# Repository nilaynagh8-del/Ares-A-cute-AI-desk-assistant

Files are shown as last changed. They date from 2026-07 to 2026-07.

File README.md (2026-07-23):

# Ares

A desk robot companion with two big, glowing ocean-blue eyes on a round screen.
Ares listens through its onboard microphone, thinks on your PC with **Gemini Live**,
and speaks back through your computer speakers — while its eyes animate idle,
listening, and speaking states.

---

## Quick Start

1. **Flash the firmware** — see [Docs/flashing.md](Docs/flashing.md).
2. **Install the desktop app** — see [Desktop/README.md](Desktop/README.md).
3. Put the robot on WiFi (USB provisioning in the app), connect by IP, paste your
   Gemini API key, and click **Start talking**.

You can also open `http://<robot-ip>/` on your phone — the ESP32 serves a web UI
that uses the robot mic and drives the eyes.

---

## Features

- **Animated robot eyes** — blink, gaze, breathe; states for idle / listening / speaking
- **Onboard PDM mic** streamed over WiFi to the desktop app (or phone web UI)
- **Gemini Live voice assistant** on your PC with web search and safe PC control tools
- **Hands-free wake word** — say "Ares" (local Vosk, no signup)
- **Swipe-down menu** on the round display — brightness slider + robot IP
- **Personality files** — edit `system.md` and `memory.md`; synced to the robot over WiFi
- **System-tray agent** — optional background auto-connect + hands-free mode
- **Camera-ready hardware path** — the ESP32-S3 Sense camera is not integrated in
  this build because the stock ribbon cable is too short for the enclosure layout

---

## Architecture

```
ESP32 mic --(WiFi TCP :8080)-->  Desktop app  -->  Gemini Live
ESP32 eyes <--(state JSON)-------               |
                                                +--> PC speakers
Phone browser --(WebSocket :81)--> robot-served page + Gemini
```

See [Docs/architecture.md](Docs/architecture.md) for ports, pins, and design notes.

---

## What is this?

Ares is a small desk character you can talk to. The ESP32-S3 + round display handles
the face, touch, and microphone. Your PC runs the voice AI (Gemini), plays audio, and
can open apps, search the web, and remember shortcuts on your behalf. Press [here](https://drive.google.com/file/d/1ACdh4I4yCxnCxKJ7vzaC96i0bJgCajry/view?usp=sharing) for a demo.

---

## Hardware

| Part | Role |
|---|---|
| Seeed XIAO ESP32-S3 **Sense** | MCU + onboard PDM microphone |
| Seeed Round Display for XIAO | GC9A01 240x240 round IPS + touch |
| MakerHawk 1000mAh 1S LiPo | Battery power |
| Custom 3D-printed enclosure | Printable files in [CAD/](CAD/) |

Full enclosure files and build notes: [CAD/](CAD/).

### Camera note

The Seeed XIAO ESP32-S3 Sense includes a camera connector/camera module, but Ares
does not currently use it. The stock camera ribbon cable is too short for this
enclosure, so the camera is not routed through the top cutout.

A future build could swap in a compatible camera module or longer ribbon cable,
route it through the top cutout, and extend the firmware/desktop bridge to send
camera frames into Gemini Live for visual analysis with `gemini-3.1-flash-live-preview`.
That would require code changes; the current release is voice-first.

---

## Repo layout

| Folder | Contents |
|---|---|
| [Firmware/](Firmware/) | Arduino sketch for the ESP32 (`RobotEyes.ino`) |
| [Desktop/](Desktop/) | Python companion app (Gemini Live, wake word, tray agent) |
| [Docs/](Docs/) | Flashing, architecture, setup |
| [CAD/](CAD/) | STEP assembly and printable enclosure STLs |

---

## Photos

| Ares on the desk | Low-light glow |
|---|---|
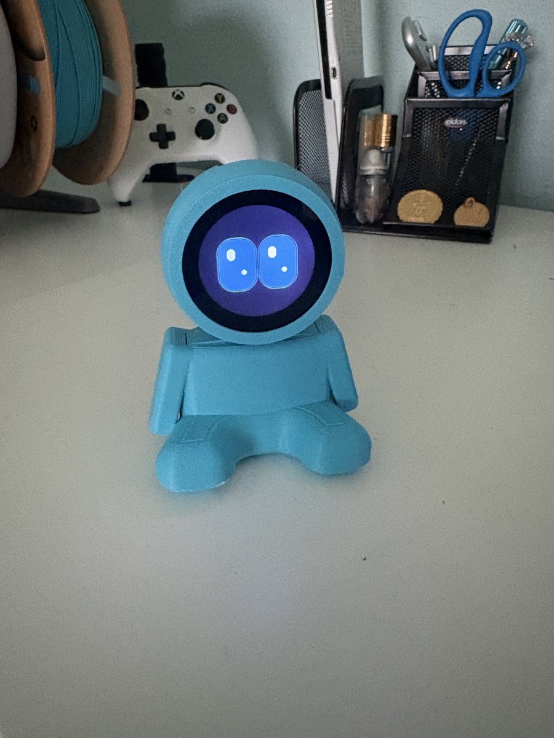
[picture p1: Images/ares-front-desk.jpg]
Ares on a desk with blue printed body and animated eyes
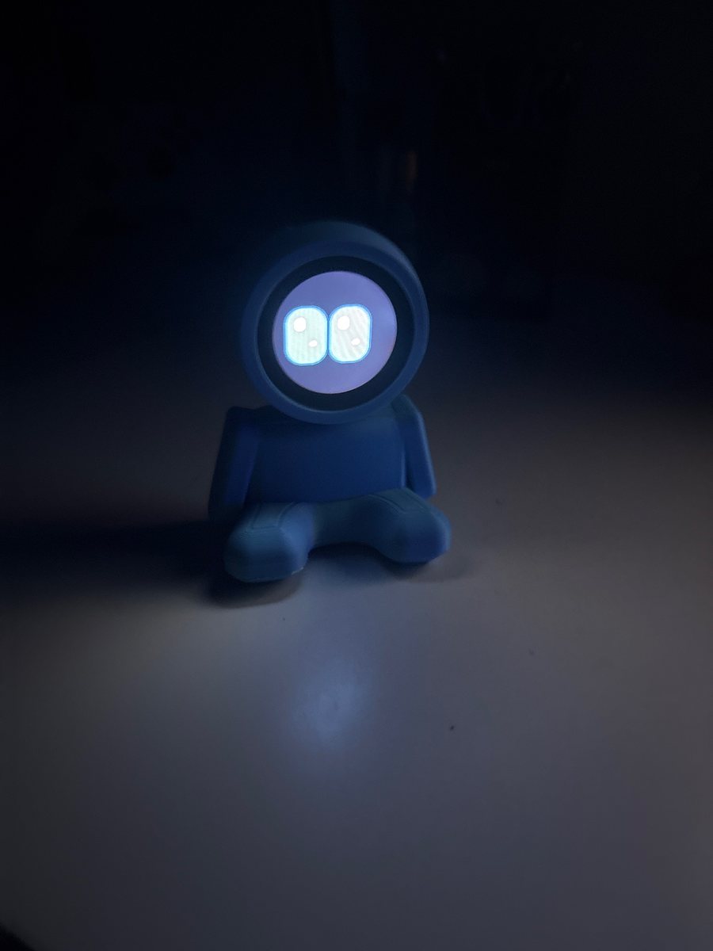
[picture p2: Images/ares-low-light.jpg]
Ares glowing in low light
|  |  |

| Front view | Battery slot | Internal electronics |
|---|---|---|
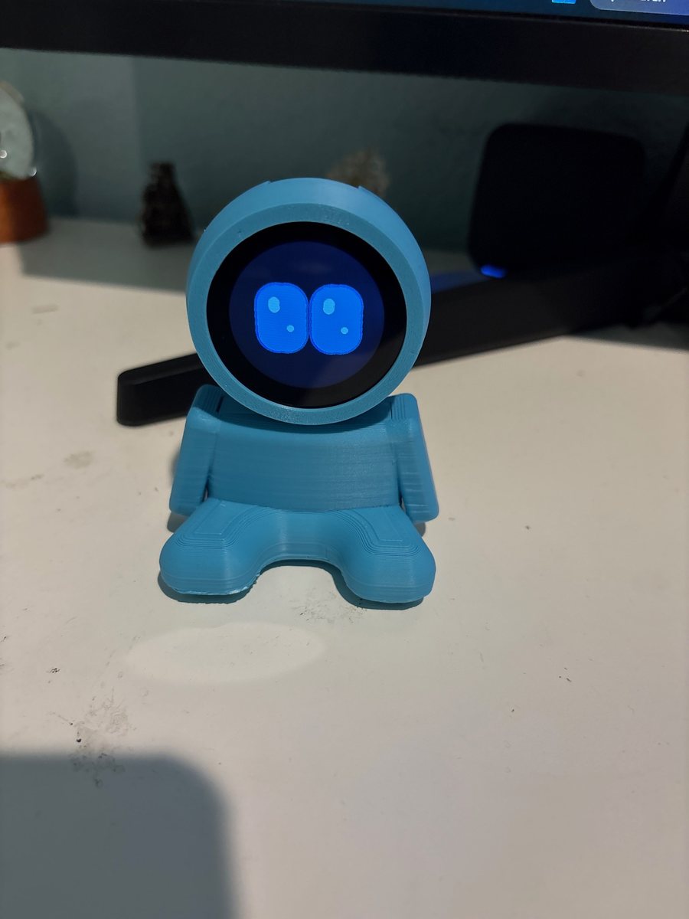
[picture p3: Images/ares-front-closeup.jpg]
Front view of Ares showing the round display and enclosure
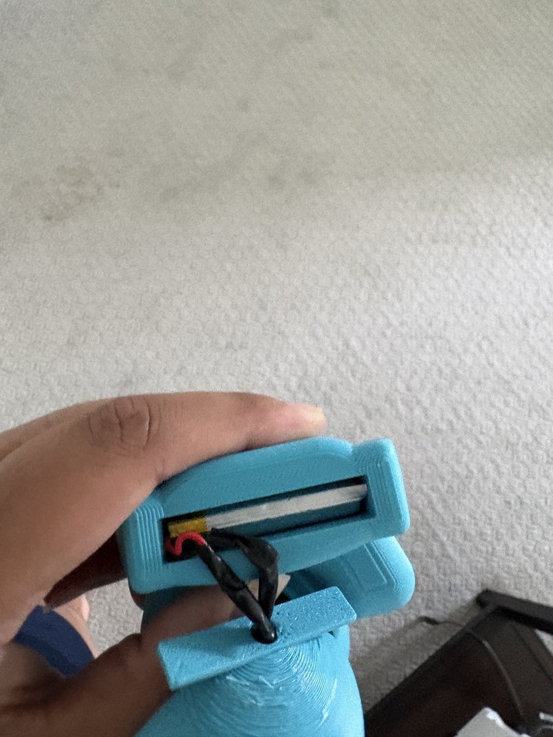
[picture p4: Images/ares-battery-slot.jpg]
Battery slot with MakerHawk 1000mAh 1S LiPo installed
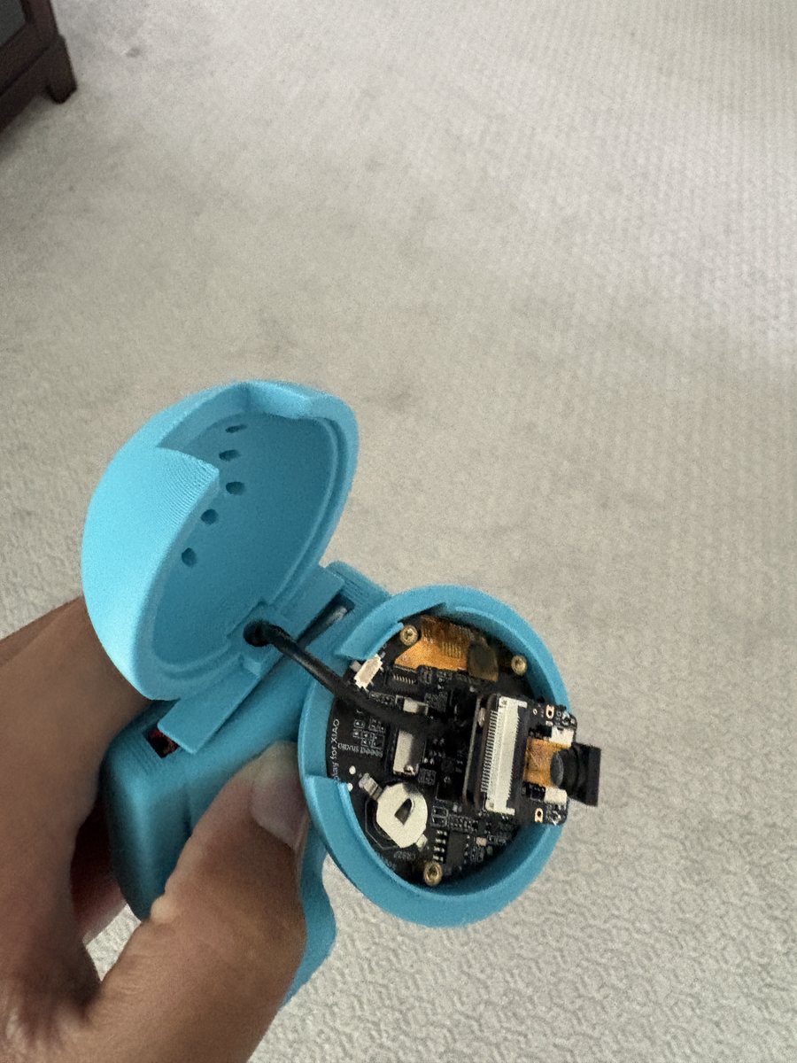
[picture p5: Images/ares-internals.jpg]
Open Ares enclosure showing Seeed XIAO ESP32-S3 Sense and round display electronics
|  |  |  |

---

## Credits

Built as a desk companion project. README structure was modeled after
[Logan Peterson's SplashPad](https://github.com/SharKingStudios/SplashPad).

Uses [Gemini Live](https://ai.google.dev/), [Vosk](https://alphacephei.com/vosk/),
and Seeed Studio hardware.

---

## Disclaimer

This project is open source. If anything you build from this does not work or has
any issues, I sincerely apologize, but at the end of the day **that's on you.**

Gemini Live requires a Google AI Studio API key with billing enabled for realtime
voice. See [Desktop/README.md](Desktop/README.md) for setup.

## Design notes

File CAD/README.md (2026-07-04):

# CAD

3D model files for the Ares enclosure.

## Files

| File | Purpose |
|---|---|
| `Ares-robot-assembled.step` | Full assembled model for reference/editing |
| `Body.stl` | Printable body/base |
| `Head-Front.stl` | Printable front half of the head |
| `Head-Back.stl` | Printable back half of the head |

The enclosure is built around the Seeed XIAO ESP32-S3 Sense, Seeed Round Display
for XIAO, and a MakerHawk 1000mAh 1S LiPo battery.

## Camera cutout

The XIAO ESP32-S3 Sense can support a camera, but this build does not integrate
the included camera because its stock ribbon cable is too short for the enclosure.
The top cutout leaves a path for a future camera build: use a compatible camera or
longer ribbon cable, route it through the cutout, and update the firmware/desktop
software to forward frames for Gemini visual analysis.

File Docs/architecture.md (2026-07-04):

# Architecture

## System overview

Ares splits work between the ESP32 (face + mic + touch) and a PC or phone (voice AI + speakers).

| Component | Runs on | Role |
|---|---|---|
| Eye animation, touch UI | ESP32 | GC9A01 display, CHSC6X/CST816 touch |
| PDM microphone | ESP32 | 16 kHz mono, streamed to clients |
| WiFi servers | ESP32 | HTTP, WebSocket, raw TCP audio |
| Gemini Live session | PC | Voice AI, search, PC tools |
| Speaker output | PC / phone | ESP32 has no DAC |
| Phone web UI | ESP32 (`page.h`) | Served at `http://<robot-ip>/` |

## Network ports (ESP32)

| Port | Protocol | Purpose |
|---|---|---|
| 80 | HTTP | Phone page, `/system.md`, `/memory.md` (NVS-backed) |
| 81 | WebSocket | Phone mic relay + eye state |
| 8080 | TCP | Raw PCM mic stream for desktop app |
| 8081 | HTTP | Status JSON (battery — unreliable on some boards) |

## Pin map (XIAO ESP32-S3 → Round Display)

| Function | XIAO pin | GPIO |
|---|---|---|
| TFT CS | D1 | 2 |
| TFT DC | D3 | 4 |
| SCLK | D8 | 7 |
| MOSI | D10 | 9 |
| MISO | D9 | 8 |
| Backlight PWM | D6 | 43 |
| Touch SDA/SCL | D4/D5 | 5/6 |
| Touch INT | D7 | 44 |
| PDM mic CLK/DATA | — | 42/41 |

## Personality storage

`system.md` and `memory.md` live on the PC. On connect, the desktop app syncs them
to ESP32 **NVS** (namespace `persona`). The phone web UI fetches them over HTTP.

## Hardware constraints

- **No Bluetooth Classic / A2DP** — cannot pair headphones to the ESP32.
- **No speaker** — all TTS plays on the PC or phone browser.
- **Touch INT (GPIO44) is not RTC** — cannot wake from deep sleep on touch alone;
  triple-tap sleep uses a lighter power mode + restart to wake.
- **microSD** was abandoned on some cards; personality uses NVS instead.

## Desktop app flow

1. `device_link.py` — USB JSON commands for WiFi provisioning.
2. `device_stream.py` — TCP mic from robot, HTTP personality sync, eye state commands.
3. `gemini_live.py` — async Gemini Live with half-duplex (mute mic while speaking).
4. `assistant.py` — wake word (Vosk "Ares") → active conversation → re-arm after silence.
5. `pc_tools.py` — function calling: open apps/URLs/files, shortcuts, volume.

## Firmware subsystems

- **Eyes** — `drawEye()` into GFXcanvas16 (PSRAM), ~24 fps SPI push.
- **Touch** — swipe down = brightness menu; triple-tap = sleep.
- **netTask** — core 0 loop: WebSocket, TCP audio, mic capture, command JSON.

See [flashing.md](flashing.md) for toolchain details.

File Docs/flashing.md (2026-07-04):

# Flashing the firmware

## Requirements

- [Arduino IDE 2.x](https://www.arduino.cc/en/software) with **esp32** board package (3.3.x)
- Board: **Seeed XIAO ESP32S3** with **PSRAM: OPI** enabled
- Libraries (Library Manager):
  - Adafruit GC9A01A
  - Adafruit GFX Library
  - Adafruit BusIO
  - ArduinoJson 7
  - WebSockets by Markus Sattler (links2004) 2.7.x

## Arduino CLI (optional)

If you use the Arduino IDE bundled CLI:

```powershell
$cli = "$env:LOCALAPPDATA\Programs\Arduino IDE\resources\app\lib\backend\resources\arduino-cli.exe"
& $cli compile --fqbn esp32:esp32:XIAO_ESP32S3:PSRAM=opi "Firmware\RobotEyes"
& $cli upload  -p COM8 --fqbn esp32:esp32:XIAO_ESP32S3:PSRAM=opi "Firmware\RobotEyes"
```

Replace `COM8` with your port. **PSRAM=opi is required** for the eye framebuffer.

## WiFi credentials

Do **not** hardcode your home WiFi in the sketch for production use. Options:

1. Leave `WIFI_SSID` / `WIFI_PASS` empty in `RobotEyes.ino` and provision over USB
   from the desktop app.
2. Use the desktop app's **Send WiFi to robot over USB** — credentials are stored in
   ESP32 NVS.

The robot only supports **2.4 GHz** WiFi.

## After flashing

1. Open Serial Monitor at 115200 baud — look for the assigned IP.
2. Or swipe down on the round display — the menu shows the IP.
3. Connect from the desktop app using that IP.

## Gotchas

- Use a **USB data cable** (not charge-only). Bad cables cause "Device Descriptor Request Failed".
- Round display **KE slide switch** must connect backlight/battery or brightness PWM won't work.
- Close the desktop app's serial connection before re-flashing.
- **TFT_eSPI** is not used — it crashes on ESP32 core 3.x for this board; stick with Adafruit drivers.

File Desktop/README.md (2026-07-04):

# Robot Companion (Desktop App)

Python desktop app for the Ares desk robot. Runs **Gemini Live** voice conversation
on your PC, streams the robot's onboard mic over WiFi, and drives eye animations.

## Why the PC does the talking

The XIAO ESP32-S3 has **Bluetooth LE only (no Bluetooth Classic/A2DP)** and
**no audio DAC or speaker**, so it cannot play sound on its own. This app is the
brain + voice:

```
ESP32 mic ──(WiFi)──►  Desktop app  ──►  Gemini Live  ──►  PC speakers
ESP32 eyes ◄──(state)──┘
```

If no robot is connected, the app falls back to your PC microphone.

## Setup

```bash
cd Desktop
python -m venv .venv
.venv\Scripts\activate          # Windows
pip install -r requirements.txt
```

Copy `config.example.json` to `config.json`, or copy `.env.example` to `.env` and
add your Gemini key (free at https://aistudio.google.com/apikey).

Copy `system.md` and `memory.md` templates and edit them to define Ares's personality.

## Run

```bash
python app.py
```

1. **WiFi (USB):** plug in the robot, pick its COM port, enter WiFi credentials,
   click **Send WiFi to robot over USB**. Note the IP from the log.
2. **Connect (WiFi):** enter the robot IP and click **Connect to robot**.
3. **Talk:** paste your Gemini key, pick voice output, click **Start talking**.

For a visible console on errors, use `Run Robot Companion (debug).bat`.

## Background agent

```bash
python agent.py
```

System-tray icon: auto-connects to the saved robot IP and runs hands-free mode.

## Files

| File | Role |
|---|---|
| `app.py` | CustomTkinter GUI |
| `gemini_live.py` | Gemini Live session (mic → model → speaker) |
| `assistant.py` | Hands-free wake word + conversation loop |
| `wakeword.py` | Vosk wake word ("Ares") |
| `device_stream.py` | WiFi mic stream + personality sync |
| `device_link.py` | USB serial (WiFi provisioning) |
| `pc_tools.py` | Gemini function calling (open apps, search, volume) |
| `config.py` | Settings load/save |

## Gemini billing

The realtime Live API requires billing enabled on your Google AI project (free tier
may return quota errors). Add credits in Google AI Studio if needed.

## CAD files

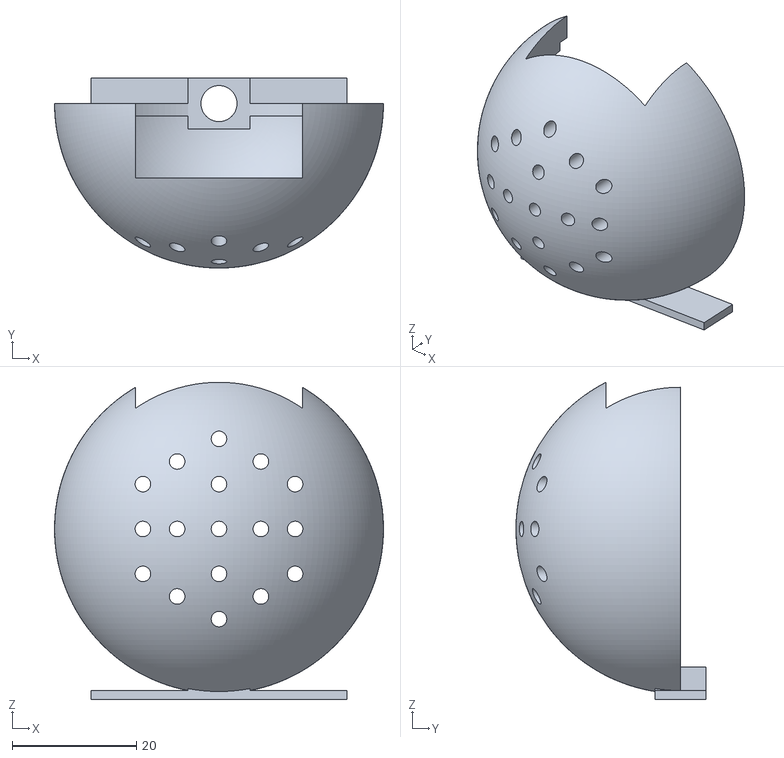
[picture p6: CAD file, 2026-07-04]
CAD/Head-Back.stl
53.0 x 30.6 x 51.1

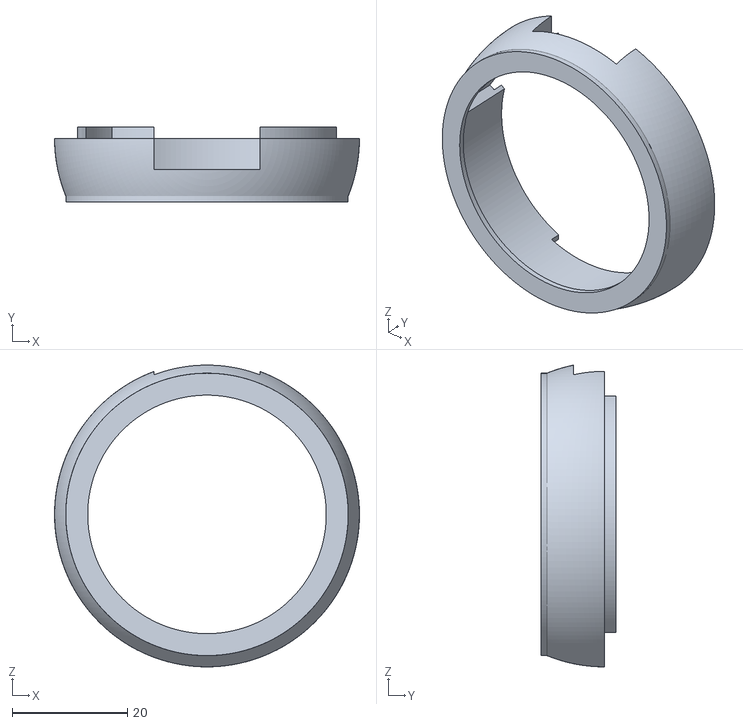
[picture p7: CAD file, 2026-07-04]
CAD/Head-Front.stl
53.0 x 13.0 x 52.4

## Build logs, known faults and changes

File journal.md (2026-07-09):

# Ares Build Journal

## June 20: Parts import + measuring

Imported all the parts into OnShape and measured the dimensions — the Seeed XIAO ESP32-S3 Sense, the round GC9A01 display, and the MakerHawk 1000mAh 1S LiPo all needed real measurements before modeling anything around them, since eyeballing dimensions on a face-shaped enclosure is a fast way to end up with a battery that doesn't fit.

**Time spent this session: 5 min**

---

## June 21: Modeling the back head

Modeled the back head shell. Splitting the head into front/back shells made sense since the round display needs to seat into a face-facing cutout, while the back needs to be hollowed out enough to route the mic/display wiring back toward the body.

back_head_cad

**Time spent this session: 1 hour**

---

## June 22: Modeling the front head

Modeled the front head shell — the half the round display actually seats into.

front_head_cad

**Time spent this session: 1 hour**

---

## June 23: Modeling the body

Modeled the body. This one needed to account for the battery bay, a wire pass-through up to the head, and mounting points for the XIAO board.

body_cad

**Time spent this session: 2 hours**

---

## June 24: First print + fit test

Printed all three parts to test fit, and — as expected — found a few things that only show up once you're holding the physical part rather than looking at it on screen.

**No spot for the screen's on/off switch.** Had to go back into the model and add a cutout for it.

**Time spent this session: 30 min**

---

## June 25: Fixing the head-to-body slot

The head-to-body slot wasn't sized right, so the head didn't seat into the body cleanly. Reworked the cutout geometry so it actually slots in.

**Time spent this session: 30 min**

---

## June 26: Reshaping the battery slot

The battery slot needed reshaping, plus a new hole to route the battery wire from the body up into the head.

**Time spent this session: 30 min**

---

## June 27: Reprint + working fit

Reprinted the parts with all the fixes from the last few sessions, and this time everything slotted together correctly.

**Time spent this session: 10 min**

---

## June 28: Extending the battery wires

The battery cable turned out to be a little too short once everything was in its final position inside the enclosure, so I extended the wires rather than redesigning the bay around a fixed cable length.

battery_bay

**Time spent this session: 30 min**

---

## June 29: Soldering XIAO headers

Soldered headers onto the XIAO ESP32-S3 so it could actually seat onto the board mounts in the enclosure.

**Time spent this session: 1 hour**

---

## June 30: Full assembly

Assembled everything — head, body, display, battery, XIAO — into one working unit for the first time.

electronics_open

**Time spent this session: 30 min**

---

## July 1: Firmware/software troubleshooting

Spent this session troubleshooting the code to get everything talking to each other correctly — display driving, mic streaming, and getting the board to boot into a working state. Used AI assistance for parts of this rather than debugging blind.

final_assembly

**Time spent this session: 1 hour 30 min**

---

*Ares, up and running.*

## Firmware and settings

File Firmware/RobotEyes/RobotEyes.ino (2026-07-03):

/* ============================================================================
 *  Cute Robot Eyes  +  swipe-down brightness menu
 *  Board : Seeed XIAO ESP32-S3
 *  Screen: Seeed Studio Round Display for XIAO  (GC9A01 240x240, IPS)
 *  Touch : auto-detect CST816 (0x15) or CHSC6X (0x2E) on I2C (D4/D5)
 *  Render: Adafruit_GFX 240x240 framebuffer (GFXcanvas16), pushed via SPI
 *
 *  Interaction:
 *    - Two big oval robot eyes blink, breathe and glance around on their own.
 *    - Swipe DOWN  -> brightness panel slides in from the top.
 *    - Drag finger left/right on the panel -> set brightness (live).
 *    - Swipe UP (or tap below the panel) -> close it.
 *
 *  NOTE: the round display board has a small "KE" slide switch. It must be on
 *  the side that connects the backlight/battery, or the brightness PWM (D6)
 *  won't physically reach the LED. If the slider does nothing, flip that switch.
 * ========================================================================== */

#include <Adafruit_GFX.h>
#include <Adafruit_GC9A01A.h>
#include <SPI.h>
#include <Wire.h>
#include <WiFi.h>
#include <ESPmDNS.h>
#include <Preferences.h>
#include <ESP_I2S.h>
#include <ArduinoJson.h>
#include <WebServer.h>
#include <WebSocketsServer.h>
#include "esp_sleep.h"
#include "driver/gpio.h"
#include "page.h"

/* ---------- Pins ---------------------------------------------------------- */
#define PIN_TFT_DC    4    // D3
#define PIN_TFT_CS    2    // D1
#define PIN_TFT_SCK   7    // D8
#define PIN_TFT_MOSI  9    // D10
#define PIN_TFT_MISO  8    // D9  (needed for the SD card)
#define PIN_SD_CS     3    // D2  (microSD chip-select on the round display)
#define PIN_TFT_RST   -1
#define PIN_BL        43   // D6  -> backlight (PWM)
#define PIN_TOUCH_SDA 5    // D4
#define PIN_TOUCH_SCL 6    // D5
#define PIN_TOUCH_INT 44   // D7  (active low)

/* ---------- Orientation (display + touch rotate together) --------------- */
#define SCREEN_ROT    1   // 0,1,2,3 = 0/90/180/270 deg.  Try 3 for the other way.
/* fine touch tweaks (usually leave 0) */
#define TOUCH_INV_X   0
#define TOUCH_INV_Y   0

/* ---------- WiFi (hardcoded auto-join) ---------------------------------- *
 * Fill these to join your network automatically on boot.
 * MUST be a 2.4 GHz network - the ESP32-S3 has no 5 GHz radio.            */
#define WIFI_SSID ""   // optional boot fallback — prefer USB provisioning or NVS
#define WIFI_PASS ""

Adafruit_GC9A01A tft(&SPI, PIN_TFT_DC, PIN_TFT_CS, PIN_TFT_RST);
GFXcanvas16      canvas(240, 240);

static const int16_t W = 240, H = 240, CX = 120, CY = 120;

/* ---------- Colour helpers (RGB565) -------------------------------------- */
static inline uint16_t rgb(uint8_t r, uint8_t g, uint8_t b) {
  return ((r & 0xF8) << 8) | ((g & 0xFC) << 3) | (b >> 3);
}
const uint16_t COL_BG     = rgb(2, 4, 8);
const uint16_t COL_EYE    = rgb(16, 110, 170);   // ocean blue
const uint16_t COL_GLOW1  = rgb(8, 48, 86);
const uint16_t COL_GLOW2  = rgb(4, 22, 44);
const uint16_t COL_HI     = rgb(120, 185, 225);
const uint16_t COL_PANEL  = rgb(14, 20, 32);
const uint16_t COL_BORDER = rgb(42, 78, 100);
const uint16_t COL_TRACK  = rgb(40, 50, 66);
const uint16_t COL_TEXT   = rgb(200, 236, 255);

/* live (brightness-scaled) palette - recomputed every frame */
uint16_t cBG, cEye, cGlow1, cGlow2, cHi, cPanel, cBorder, cTrack, cText;
static uint16_t dimColor(uint16_t c, float s) {
  int r = (int)(((c >> 11) & 0x1F) * s);
  int g = (int)(((c >> 5) & 0x3F) * s);
  int b = (int)((c & 0x1F) * s);
  return ((r & 0x1F) << 11) | ((g & 0x3F) << 5) | (b & 0x1F);
}

/* ---------- Backlight (ledc) --------------------------------------------- */
static void backlightInit() {
#if ESP_ARDUINO_VERSION_MAJOR >= 3
  bool ok = ledcAttach(PIN_BL, 5000, 8);
  Serial.printf("[bl] ledcAttach(GPIO%d) = %s\n", PIN_BL, ok ? "ok" : "FAIL");
#else
  ledcSetup(0, 5000, 8);
  ledcAttachPin(PIN_BL, 0);
#endif
}
static void backlightWrite(uint8_t v) {
#if ESP_ARDUINO_VERSION_MAJOR >= 3
  ledcWrite(PIN_BL, v);
#else
  ledcWrite(0, v);
#endif
}

/* ---------- Touch --------------------------------------------------------- */
uint8_t touchAddr = 0;   // 0x15 = CST816, 0x2E = CHSC6X, 0 = none

static void i2cScan(const char *tag) {
  uint8_t found = 0;
  Serial.printf("[i2c] scan (%s):", tag);
  for (uint8_t a = 0x08; a < 0x78; a++) {
    Wire.beginTransmission(a);
    if (Wire.endTransmission() == 0) { Serial.printf(" 0x%02X", a); found++; }
  }
  if (!found) Serial.print(" (no devices)");
  Serial.println();
  if (touchAddr == 0) {
    Wire.beginTransmission(0x2E);
    if (Wire.endTransmission() == 0) touchAddr = 0x2E;
    else { Wire.beginTransmission(0x15);
           if (Wire.endTransmission() == 0) touchAddr = 0x15; }
    if (touchAddr) Serial.printf("[touch] using chip @ 0x%02X\n", touchAddr);
  }
}

// read one specific chip's report; true + raw coords if a finger is present
static bool readChip(uint8_t addr, int16_t &rx, int16_t &ry) {
  if (addr == 0x2E) {                       // CHSC6X
    uint8_t t[5] = {0};
    if (Wire.requestFrom((uint8_t)0x2E, (uint8_t)5) != 5) return false;
    for (uint8_t i = 0; i < 5; i++) t[i] = Wire.read();
    if (t[0] != 0x01) return false;
    rx = t[2]; ry = t[4];
    return true;
  } else {                                  // CST816 (0x15)
    Wire.beginTransmission(0x15);
    Wire.write(0x01);
    if (Wire.endTransmission(false) != 0) return false;
    if (Wire.requestFrom((uint8_t)0x15, (uint8_t)6) != 6) return false;
    uint8_t t[6];
    for (uint8_t i = 0; i < 6; i++) t[i] = Wire.read();
    if (!(t[1] & 0x0F)) return false;
    rx = ((t[2] & 0x0F) << 8) | t[3];
    ry = ((t[4] & 0x0F) << 8) | t[5];
    return true;
  }
}

// true while a finger is down; fills mapped screen coords.
// Detects the touch chip on first real contact (address scans are unreliable
// for these controllers, but a register read while INT is low works).
static bool touchRead(int16_t &sx, int16_t &sy) {
  if (digitalRead(PIN_TOUCH_INT) == HIGH) return false;   // INT idle high
  int16_t rx = 0, ry = 0;
  bool ok = false;

  if (touchAddr && readChip(touchAddr, rx, ry)) ok = true;
  if (!ok) {                                              // (re)detect
    if (readChip(0x2E, rx, ry)) { touchAddr = 0x2E; ok = true; }
    else if (readChip(0x15, rx, ry)) { touchAddr = 0x15; ok = true; }
    if (ok) Serial.printf("[touch] locked chip 0x%02X\n", touchAddr);
  }
  if (!ok) return false;

  // rotate raw (native) coords to match the displayed orientation
  int16_t mx, my;
  switch (SCREEN_ROT & 3) {
    case 0:  mx = rx;           my = ry;           break;
    case 1:  mx = ry;           my = (W - 1) - rx; break;
    case 2:  mx = (W - 1) - rx; my = (H - 1) - ry; break;
    default: mx = (H - 1) - ry; my = rx;           break;
  }
  if (TOUCH_INV_X) mx = (W - 1) - mx;
  if (TOUCH_INV_Y) my = (H - 1) - my;
  sx = mx; sy = my;
  return true;
}

/* ---------- Animation / UI state ----------------------------------------- */
float gazeX = 0, gazeY = 0, gazeTX = 0, gazeTY = 0;
uint32_t nextGazeMs = 0;

float    blink = 1.0f;          // 1 = open, ~0.08 = closed
int      blinkPhase = 0;        // 0 idle, 1 closing, 2 opening
uint32_t nextBlinkMs = 0;

bool  menuOpen = false;
float menuShown = 0.0f;         // 0 hidden -> 1 fully down
const int16_t PANEL_H = 150;

/* battery readout (filled by monitorTask) */
volatile int  g_batPct = 0;
volatile float g_batV = 0;
volatile bool g_charging = false, g_charged = false, g_haveBat = false;

float   brightFrac = 0.80f;     // 0..1
const uint8_t BL_MIN = 12;      // never fully black

/* shared with the network task (assistant) */
volatile int  eyeState = 0;     // 0 idle, 1 listening, 2 speaking
volatile bool lowPower = false;
volatile bool wifiConnected = false;
volatile bool screenSleep = false;   // triple-tap to turn the screen off
char g_ip[24] = "connecting...";     // shown in the swipe-down menu
#define ROT_DEG 0                    // fixed eye tilt in degrees (flip sign for the other way)
float g_rc = 1.0f, g_rs = 0.0f;      // cos/sin of ROT_DEG, set in setup

static float powerScale() { return lowPower ? 0.45f : 1.0f; }

static void applyBrightness() {
  if (screenSleep) { backlightWrite(0); return; }
  float b = brightFrac * powerScale();
  backlightWrite((uint8_t)(BL_MIN + b * (255 - BL_MIN)));
}

// recompute the on-screen palette so brightness also works in software
// (covers boards where the D6 backlight line isn't routed to the LED)
static void computePalette() {
  float s = (0.18f + 0.82f * brightFrac) * powerScale();   // content never fully black
  cBG = COL_BG;                           // background stays black
  cEye = dimColor(COL_EYE, s);
  cGlow1 = dimColor(COL_GLOW1, s);
  cGlow2 = dimColor(COL_GLOW2, s);
  cHi = dimColor(COL_HI, s);
  cPanel = dimColor(COL_PANEL, s);
  cBorder = dimColor(COL_BORDER, s);
  cTrack = dimColor(COL_TRACK, s);
  cText = dimColor(COL_TEXT, s);
}

/* gesture tracking */
bool     touching = false;
int16_t  tStartX, tStartY, tCurX, tCurY;
uint32_t lastTouchMs = 0, tDownMs = 0, lastTapMs = 0;
uint8_t  tapCount = 0;
const int16_t SWIPE = 34;

uint32_t lastScanMs = 0, frames = 0, lastFpsMs = 0;

/* ---------- Eye drawing --------------------------------------------------- */
const int16_t EYE_HW = 37, EYE_HH = 52, EYE_R = 30;
const int16_t EYE_LX = 78, EYE_RX = 162;

static int16_t imin(int16_t a, int16_t b) { return a < b ? a : b; }

// rotate a screen point around the screen centre by the fixed enclosure tilt
static void rotpt(int16_t px, int16_t py, int16_t &ox, int16_t &oy) {
  float dx = px - CX, dy = py - CY;
  ox = (int16_t)lroundf(g_rc * dx - g_rs * dy) + CX;
  oy = (int16_t)lroundf(g_rs * dx + g_rc * dy) + CY;
}

// filled rounded rect centred at (cx,cy), drawn tilted (triangles + corner circles)
static void fillTiltRR(int16_t cx, int16_t cy, int16_t hw, int16_t hh, int16_t r, uint16_t col) {
  if (r > hw) r = hw;
  if (r > hh) r = hh;
  int16_t ax, ay, bx, by, c2x, c2y, d2x, d2y;
  rotpt(cx - hw, cy - (hh - r), ax, ay);   rotpt(cx + hw, cy - (hh - r), bx, by);
  rotpt(cx + hw, cy + (hh - r), c2x, c2y); rotpt(cx - hw, cy + (hh - r), d2x, d2y);
  canvas.fillTriangle(ax, ay, bx, by, c2x, c2y, col);
  canvas.fillTriangle(ax, ay, c2x, c2y, d2x, d2y, col);
  rotpt(cx - (hw - r), cy - hh, ax, ay);   rotpt(cx + (hw - r), cy - hh, bx, by);
  rotpt(cx + (hw - r), cy + hh, c2x, c2y); rotpt(cx - (hw - r), cy + hh, d2x, d2y);
  canvas.fillTriangle(ax, ay, bx, by, c2x, c2y, col);
  canvas.fillTriangle(ax, ay, c2x, c2y, d2x, d2y, col);
  int16_t px, py;
  rotpt(cx - (hw - r), cy - (hh - r), px, py); canvas.fillCircle(px, py, r, col);
  rotpt(cx + (hw - r), cy - (hh - r), px, py); canvas.fillCircle(px, py, r, col);
  rotpt(cx + (hw - r), cy + (hh - r), px, py); canvas.fillCircle(px, py, r, col);
  rotpt(cx - (hw - r), cy + (hh - r), px, py); canvas.fillCircle(px, py, r, col);
}

static void drawEye(int16_t cx, int16_t cy, int16_t hw, int16_t hh, float open) {
  int16_t eh = (int16_t)(hh * open);
  if (eh < 3) eh = 3;
  int16_t r = imin(EYE_R, imin(hw, eh));
  fillTiltRR(cx, cy, hw + 4, eh + 4, r + 4, cGlow1);   // single glow halo (faster)
  fillTiltRR(cx, cy, hw, eh, r, cEye);
  if (open > 0.55f) {
    int16_t hx = cx - hw * 0.32f;
    int16_t hy = cy - eh * 0.42f;
    fillTiltRR(hx, hy, 8, 12, 8, cHi);
    int16_t sx, sy;
    rotpt(cx + hw * 0.36f, cy + eh * 0.30f, sx, sy);
    canvas.fillCircle(sx, sy, 5, cHi);
  }
}

static void textCentered(const char *s, int16_t cyc, uint8_t size, uint16_t col) {
  int16_t w = strlen(s) * 6 * size, h = 8 * size;
  canvas.setTextSize(size);
  canvas.setTextColor(col);
  canvas.setCursor(CX - w / 2, cyc - h / 2);
  canvas.print(s);
}

/* ---------- Brightness panel --------------------------------------------- */
static void drawSun(int16_t x, int16_t y, int16_t r, uint16_t c) {
  canvas.fillCircle(x, y, r, c);
  for (int i = 0; i < 8; i++) {
    float a = i * PI / 4.0f;
    canvas.drawLine(x + cosf(a) * (r + 3), y + sinf(a) * (r + 3),
                    x + cosf(a) * (r + 6), y + sinf(a) * (r + 6), c);
  }
}

static void drawBattery(int16_t x, int16_t y, int16_t w, int16_t h,
                        int pct, bool charged) {
  uint16_t col = charged ? rgb(70, 205, 130)
                         : (pct < 20 ? rgb(225, 95, 80) : cEye);
  canvas.drawRoundRect(x, y, w, h, 3, col);
  canvas.fillRect(x + w, y + h / 3, 3, h / 3, col);          // + terminal
  int fw = (w - 4) * pct / 100;
  if (fw < 0) fw = 0; else if (fw > w - 4) fw = w - 4;
  canvas.fillRect(x + 2, y + 2, fw, h - 4, col);
}

static void drawMenu() {
  if (menuShown < 0.02f) return;
  int16_t cb = (int16_t)(menuShown * PANEL_H);   // panel bottom edge

  canvas.fillRoundRect(-30, cb - PANEL_H - 40, W + 60, PANEL_H + 40, 28, cPanel);
  canvas.drawFastHLine(8, cb, W - 16, cBorder);

  textCentered("BRIGHTNESS", cb - 118, 2, cText);

  const int16_t x0 = 54, x1 = 186, sy = cb - 90, th = 12;
  drawSun(34, sy, 4, cTrack);
  drawSun(206, sy, 6, cEye);
  canvas.fillRoundRect(x0, sy - th / 2, x1 - x0, th, th / 2, cTrack);
  int16_t fillW = (int16_t)((x1 - x0) * brightFrac);
  if (fillW < th) fillW = th;
  canvas.fillRoundRect(x0, sy - th / 2, fillW, th, th / 2, cEye);
  int16_t knobX = x0 + (int16_t)((x1 - x0) * brightFrac);
  canvas.fillCircle(knobX, sy, 11, cHi);
  canvas.drawCircle(knobX, sy, 11, cEye);

  char pct[8];
  snprintf(pct, sizeof(pct), "%d%%", (int)roundf(brightFrac * 100));
  textCentered(pct, cb - 66, 2, cEye);

  // IP address (open this in your phone's browser)
  canvas.drawFastHLine(40, cb - 48, W - 80, cBorder);
  textCentered("open in your browser", cb - 34, 1, cTrack);
  textCentered(g_ip, cb - 14, 2, cEye);
}

/* ---------- push framebuffer to display ---------------------------------- */
static void pushCanvas() {
  tft.startWrite();
  tft.setAddrWindow(0, 0, W, H);
  tft.writePixels(canvas.getBuffer(), (uint32_t)W * H);
  tft.endWrite();
}

/* ===================== Assistant: WiFi + onboard PDM mic =================
 * The device streams its mic (16 kHz / 16-bit / mono PCM) over a raw TCP
 * socket to the companion app, and reads newline-delimited JSON commands
 * back (eye state / brightness / low-power / wifi). Discoverable via mDNS as
 * "robot-eyes.local" / service _roboteyes._tcp on port 8080.
 * ====================================================================== */
#define AUDIO_PORT 8080
#define MIC_GAIN   6          // PDM mic is quiet; amplify (tune if clipping)

Preferences prefs;
WiFiServer  audioServer(AUDIO_PORT);
WebSocketsServer wsServer(81);     // phone app: robot mic out + eye-state in
I2SClass    I2S;
char wifiSsid[33] = "";
char wifiPass[65] = "";

static void loadWifi() {
  prefs.begin("robot", true);
  prefs.getString("ssid", "").toCharArray(wifiSsid, sizeof(wifiSsid));
  prefs.getString("pass", "").toCharArray(wifiPass, sizeof(wifiPass));
  prefs.end();
}

static void saveWifi(const char *s, const char *p) {
  prefs.begin("robot", false);
  prefs.putString("ssid", s);
  prefs.putString("pass", p);
  prefs.end();
  strncpy(wifiSsid, s, sizeof(wifiSsid) - 1);
  strncpy(wifiPass, p, sizeof(wifiPass) - 1);
  Serial.printf("[wifi] saved '%s', connecting...\n", wifiSsid);
  WiFi.disconnect();
  WiFi.begin(wifiSsid, wifiPass);
}

// JSON control commands from USB serial OR the connected app (over TCP)
static void handleCommand(const char *line) {
  JsonDocument doc;
  if (deserializeJson(doc, line)) return;
  const char *cmd = doc["cmd"];
  if (!cmd) return;
  if (!strcmp(cmd, "state")) {
    const char *v = doc["value"] | "idle";
    eyeState = !strcmp(v, "speaking") ? 2 : (!strcmp(v, "listening") ? 1 : 0);
  } else if (!strcmp(cmd, "brightness")) {
    float f = doc["value"] | 0.8f;
    brightFrac = f < 0 ? 0 : (f > 1 ? 1 : f);
    applyBrightness();
  } else if (!strcmp(cmd, "lowpower")) {
    lowPower = doc["value"] | false;
    applyBrightness();
  } else if (!strcmp(cmd, "wifi")) {
    const char *s = doc["ssid"] | "";
    const char *p = doc["pass"] | "";
    if (strlen(s)) saveWifi(s, p);
  } else if (!strcmp(cmd, "ping")) {
    Serial.println("[net] pong");
  }
}

// WebSocket (phone app): text frames carry eye-state commands
static void wsEvent(uint8_t num, WStype_t type, uint8_t *payload, size_t len) {
  if (type == WStype_CONNECTED) {
    Serial.println("[ws] phone connected");
    if (eyeState == 0) eyeState = 1;
  } else if (type == WStype_DISCONNECTED) {
    Serial.println("[ws] phone disconnected");
  } else if (type == WStype_TEXT) {
    String s; s.reserve(len);
    for (size_t i = 0; i < len; i++) s += (char)payload[i];
    handleCommand(s.c_str());
  }
}

// WiFi event logging - reason codes tell us why a join fails
static void onWiFiEvent(WiFiEvent_t event, WiFiEventInfo_t info) {
  if (event == ARDUINO_EVENT_WIFI_STA_DISCONNECTED)
    Serial.printf("[wifi] disconnected reason=%d (201=AP-not-found, 15/2/3=bad-password)\n",
                  info.wifi_sta_disconnected.reason);
  else if (event == ARDUINO_EVENT_WIFI_STA_GOT_IP) {
    Serial.print("[wifi] GOT IP -> ");
    Serial.println(WiFi.localIP());
  }
}

// Core-0 task: onboard PDM mic -> TCP client; JSON commands TCP -> device
static void netTask(void *arg) {
  I2S.setPinsPdmRx(42, 41);   // XIAO ESP32-S3 Sense: CLK=42, DATA=41
  if (!I2S.begin(I2S_MODE_PDM_RX, 16000, I2S_DATA_BIT_WIDTH_16BIT,
                 I2S_SLOT_MODE_MONO))
    Serial.println("[mic] I2S begin FAILED");
  else
    Serial.println("[mic] PDM mic ready (16 kHz mono)");

  static uint8_t buf[1024];   // 512 samples = ~32 ms
  String netBuf;
  bool announced = false;
  WiFiClient client;          // optional desktop (raw-TCP) client

  for (;;) {
    if (screenSleep) {                          // asleep: stop mic + wifi work entirely
      wifiConnected = false;
      announced = false;
      vTaskDelay(pdMS_TO_TICKS(300));
      continue;
    }
    if (WiFi.status() != WL_CONNECTED) {
      wifiConnected = false;
      announced = false;
      strcpy(g_ip, "no wifi");
      static uint32_t lastTry = 0;
      if (millis() - lastTry > 9000) {
        lastTry = millis();
        Serial.printf("[wifi] status=%d, retrying join to '%s'\n",
                      WiFi.status(), wifiSsid);
        WiFi.disconnect();
        WiFi.begin(wifiSsid, wifiPass);
      }
      vTaskDelay(pdMS_TO_TICKS(300));
      continue;
    }
    if (!announced) {
      announced = true;
      wifiConnected = true;
      Serial.print("[wifi] connected  IP ");
      Serial.println(WiFi.localIP());
      WiFi.localIP().toString().toCharArray(g_ip, sizeof(g_ip));
      if (MDNS.begin("robot-eyes")) {
        MDNS.addService("roboteyes", "tcp", AUDIO_PORT);
        Serial.println("[mdns] robot-eyes.local advertised");
      }
      audioServer.begin();
      wsServer.begin();
      wsServer.onEvent(wsEvent);
    }

    wsServer.loop();                                  // phone WS protocol

    if (!client || !client.connected()) {             // accept a desktop client
      WiFiClient c = audioServer.available();
      if (c) { client = c; netBuf = "";
               Serial.println("[net] desktop app connected");
               if (eyeState == 0) eyeState = 1; }
    }

    size_t n = I2S.readBytes((char *)buf, sizeof(buf));   // blocks ~32 ms
    if (n) {
      int16_t *s = (int16_t *)buf;
      for (size_t i = 0; i < n / 2; i++) {
        int v = s[i] * MIC_GAIN;
        s[i] = v > 32767 ? 32767 : (v < -32768 ? -32768 : v);
      }
      if (client && client.connected()) client.write(buf, n);  // -> desktop app
      wsServer.broadcastBIN(buf, n);                           // -> phone(s)
    }

    if (client && client.connected()) {
      while (client.available()) {
        char c = client.read();
        if (c == '\n') { if (netBuf.length()) { handleCommand(netBuf.c_str()); netBuf = ""; } }
        else if (c != '\r') { netBuf += c; if (netBuf.length() > 300) netBuf = ""; }
      }
    }
  }
}
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
void loop() {
  uint32_t now = millis();

  // JSON control commands over USB serial (WiFi provisioning, manual control)
  static String sb;
  while (Serial.available()) {
    char c = Serial.read();
    if (c == '\n') { if (sb.length()) { handleCommand(sb.c_str()); sb = ""; } }
    else if (c != '\r') { sb += c; if (sb.length() > 300) sb = ""; }
  }

  static bool httpUp = false;
  if (wifiConnected && !httpUp) {
    httpRoutes(); http.begin(); httpUp = true;
    Serial.println("[http] config server on :80");
  }
  if (httpUp) http.handleClient();

  handleTouch(now);
  updateEyes(now);
  menuShown += ((menuOpen ? 1.0f : 0.0f) - menuShown) * 0.25f;

  if (!screenSleep) {
  computePalette();
  canvas.fillScreen(cBG);
  float breathe = sinf(now * 0.0018f);
  int16_t cy = CY + (int16_t)(breathe * 2) + (int16_t)gazeY;
  int16_t hh = EYE_HH + (int16_t)(breathe * 3);
  int st = eyeState;
  if (st == 1) hh += 5;                                 // listening: alert/wider
  else if (st == 2) {                                   // speaking: lively bounce
    hh += (int16_t)(sinf(now * 0.030f) * 7) + 3;
    cy += (int16_t)(sinf(now * 0.022f) * 3);
  }
  drawEye(EYE_LX + (int16_t)gazeX, cy, EYE_HW, hh, blink);
  drawEye(EYE_RX + (int16_t)gazeX, cy, EYE_HW, hh, blink);
  drawMenu();
  pushCanvas();
  }

  frames++;
  if (now - lastFpsMs >= 3000) {
    Serial.printf("[fps] %.1f  wifi=%d sleep=%d bright=%.2f\n",
                  frames * 1000.0f / (now - lastFpsMs),
                  wifiConnected, screenSleep, brightFrac);
    frames = 0; lastFpsMs = now;
  }

  // NOTE: esp_light_sleep_start() was tried here for deeper power savings but froze
  // the board solid (USB/CDC doesn't survive light sleep on this chip) - reverted to
  // a plain idle spin. WiFi is still off during screenSleep, which is the real win.
  if (screenSleep) delay(120);
  else if (lowPower) delay(80);      // throttle frame rate to save power
}

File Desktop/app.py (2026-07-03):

"""Robot Companion - desktop app (modern customtkinter UI).

  * Provisions the robot's WiFi over USB, then connects to it on your network.
  * Wake word "Ares" (Porcupine) -> hands-free back-and-forth with Gemini.
  * Streams the robot's onboard mic; plays the reply on a PC output you pick.
  * Web search + personality (system.md / memory.md); battery + eye states.

Run:  python app.py
"""
import queue
import threading
import tkinter as tk
from tkinter import filedialog

import customtkinter as ctk

import assistant
import audio_io
import config
import device_stream
from device_link import DeviceLink, available_ports
from gemini_live import GeminiVoiceSession

ACCENT = "#1a78c2"
ACCENT_HOVER = "#2f93dd"
CARD = "#171d28"
MUTED = "#8aa0b2"
STATE_COLORS = {"idle": "#3a4656", "listening": "#2fae72", "speaking": "#1a8fd0"}

ctk.set_appearance_mode("dark")
ctk.set_default_color_theme("dark-blue")


class App:
    def __init__(self, root):
        self.root = root
        self.cfg = config.load()
        self.session = None
        self.assistant = None
        self.pc_mic = None
        self.mic_queue = None
        self.serial = DeviceLink(on_log=self._log_threadsafe)
        self.stream = device_stream.DeviceStream(
            on_log=self._log_threadsafe, on_status=self._status_threadsafe)
        self._found = []
        self._found_labels = []
        self._in_devs = []
        self._out_devs = []
        self._ports = []
        self._ui_queue = queue.Queue()

        root.title("Robot Companion")
        root.geometry("560x820")
        root.minsize(520, 640)

        self._build_ui()
        self._refresh_devices()
        self._refresh_ports()
        self.root.after(80, self._drain_ui_queue)

    # ---- small builders --------------------------------------------------
    def _card(self, title):
        c = ctk.CTkFrame(self.scroll, corner_radius=14, fg_color=CARD)
        c.pack(fill="x", padx=2, pady=8)
        ctk.CTkLabel(c, text=title, font=ctk.CTkFont(size=15, weight="bold")
                     ).pack(anchor="w", padx=16, pady=(12, 4))
        return c

    def _row(self, parent, label):
        r = ctk.CTkFrame(parent, fg_color="transparent")
        r.pack(fill="x", padx=16, pady=5)
        ctk.CTkLabel(r, text=label, text_color=MUTED, width=110, anchor="w"
                     ).pack(side="left")
        return r

    def _menu(self, row, command=None):
        m = ctk.CTkOptionMenu(row, values=["(none)"], command=command,
                              fg_color="#222b3a", button_color="#2c3950",
                              button_hover_color="#37496a", dynamic_resizing=False)
        m.pack(side="left", fill="x", expand=True, padx=8)
        return m

    def _entry(self, row, var, show=None):
        e = ctk.CTkEntry(row, textvariable=var, show=show)
        e.pack(side="left", fill="x", expand=True, padx=8)
        return e

    def _btn(self, parent, text, command, accent=False, **kw):
        return ctk.CTkButton(
            parent, text=text, command=command,
            fg_color=ACCENT if accent else "#27313f",
            hover_color=ACCENT_HOVER if accent else "#323e50", **kw)

    # ---- UI --------------------------------------------------------------
    def _build_ui(self):
        header = ctk.CTkFrame(self.root, fg_color="transparent")
        header.pack(fill="x", padx=20, pady=(16, 4))
        ctk.CTkLabel(header, text="Robot Companion",
                     font=ctk.CTkFont(size=22, weight="bold")).pack(side="left")
        self.state_label = ctk.CTkLabel(header, text="idle", text_color=MUTED)
        self.state_label.pack(side="right")
        self.state_dot = ctk.CTkFrame(header, width=14, height=14, corner_radius=7,
                                      fg_color=STATE_COLORS["idle"])
        self.state_dot.pack(side="right", padx=8)

        self.scroll = ctk.CTkScrollableFrame(self.root, fg_color="transparent")
        self.scroll.pack(fill="both", expand=True, padx=14, pady=(0, 12))

        # --- Conversation ---
        conv = self._card("Conversation")
        r = self._row(conv, "Gemini key")
        self.key_var = tk.StringVar(value=self.cfg.get("gemini_api_key", ""))
        self._entry(r, self.key_var, show="•")
        self._btn(r, "Save", self._save_key, width=64).pack(side="left", padx=(0, 8))
        r = self._row(conv, "Voice out")
        self.out_menu = self._menu(r)
        self._btn(r, "Refresh", self._refresh_devices, width=80).pack(side="left", padx=(0, 8))
        r = self._row(conv, "Mic (no robot)")
        self.in_menu = self._menu(r)
        self.talk_btn = self._btn(conv, "Start talking", self._toggle_talk,
                                  accent=True, height=42,
                                  font=ctk.CTkFont(size=15, weight="bold"))
        self.talk_btn.pack(fill="x", padx=16, pady=(8, 4))
        self.mic_note = ctk.CTkLabel(conv, text="Using PC mic (connect a robot to use its mic)",
                                     text_color=MUTED, font=ctk.CTkFont(size=11))
        self.mic_note.pack(anchor="w", padx=16, pady=(0, 12))

        # --- WiFi provisioning ---
        prov = self._card("1.  Put the robot on WiFi  (USB cable)")
        r = self._row(prov, "WiFi name")
        self.ssid_var = tk.StringVar()
        self._entry(r, self.ssid_var)
        r = self._row(prov, "WiFi password")
        self.wpass_var = tk.StringVar()
        self._entry(r, self.wpass_var, show="•")
        r = self._row(prov, "USB port")
        self.port_menu = self._menu(r)
        self._btn(r, "Refresh", self._refresh_ports, width=80).pack(side="left", padx=(0, 8))
        self._btn(prov, "Send WiFi to robot over USB", self._provision
                  ).pack(fill="x", padx=16, pady=(6, 12))
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

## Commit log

2026-07-03 Initial open-source release of Ares desk robot companion.
    Firmware, desktop Gemini Live app, docs, and placeholders for CAD/BOM assets.
2026-07-04 Update hardware BOM and remove production placeholder
2026-07-04 Update README by removing image and ESP32-S3 note
    Removed image and note about ESP32-S3 limitations.
2026-07-04 Add CAD models and camera note
    [Head-Back.stl, Head-Front.stl]
